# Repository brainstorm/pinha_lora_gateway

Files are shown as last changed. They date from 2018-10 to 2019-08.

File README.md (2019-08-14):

# Mini-PCIe LoRa Gateway with PMOD and POE

This small LoRa gateway adapter (75x41mm) is motivated by the generous donation of a (n-fuse)[https://www.n-fuse.co/]'s LoRaWan [concentrator card](https://www.n-fuse.co/devices/LoRaWAN-Concentrator-Card-mini-PCIe.html). **This version of the board is meant to work with the USB firmware for the n-fuse board**:

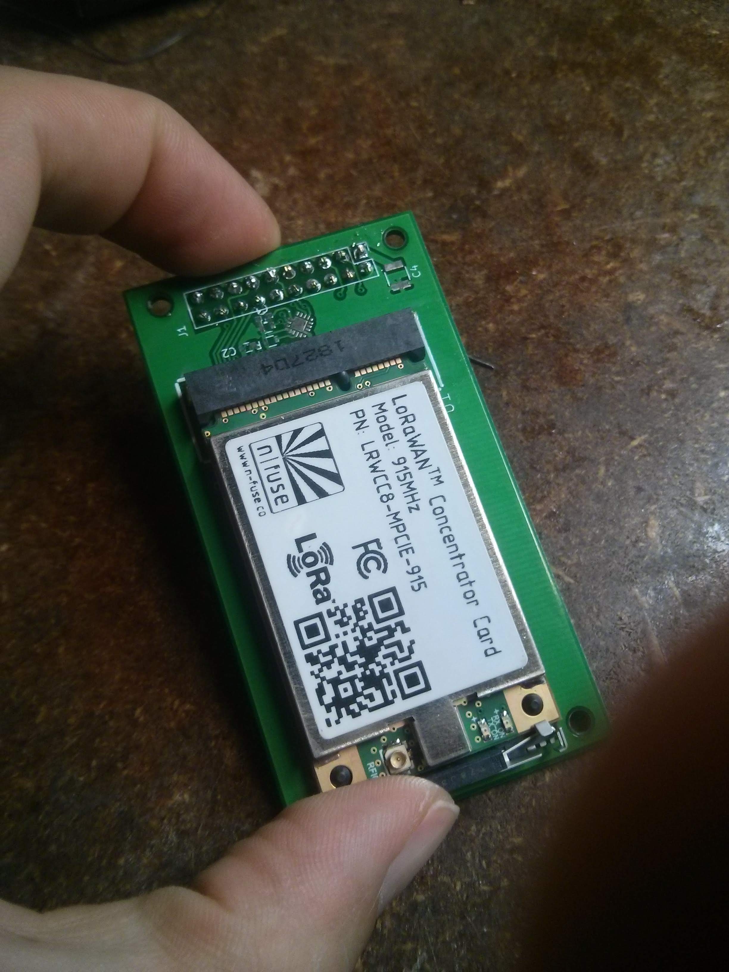
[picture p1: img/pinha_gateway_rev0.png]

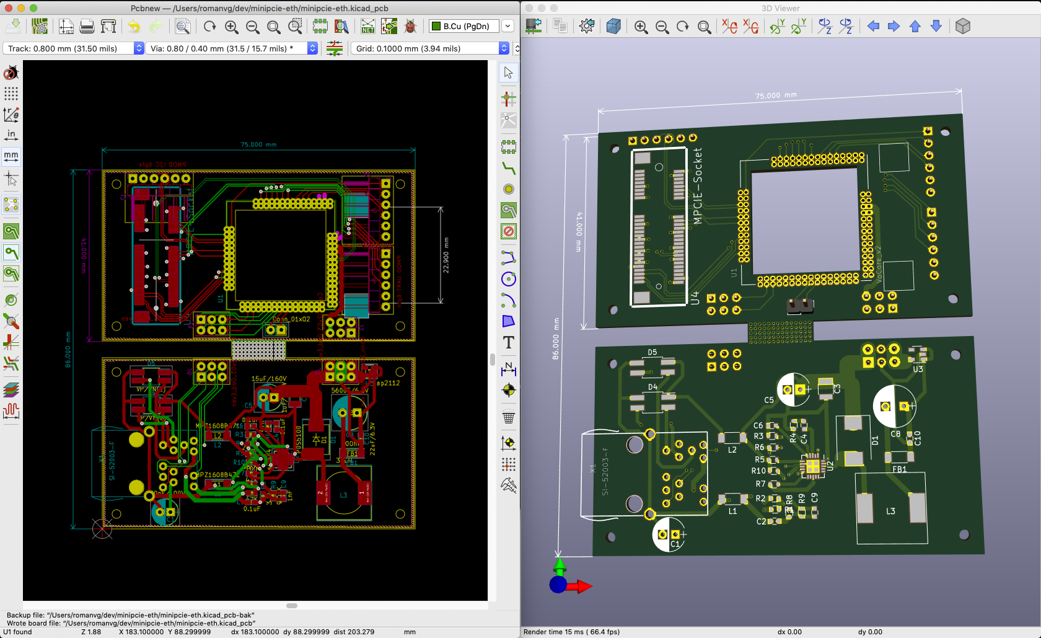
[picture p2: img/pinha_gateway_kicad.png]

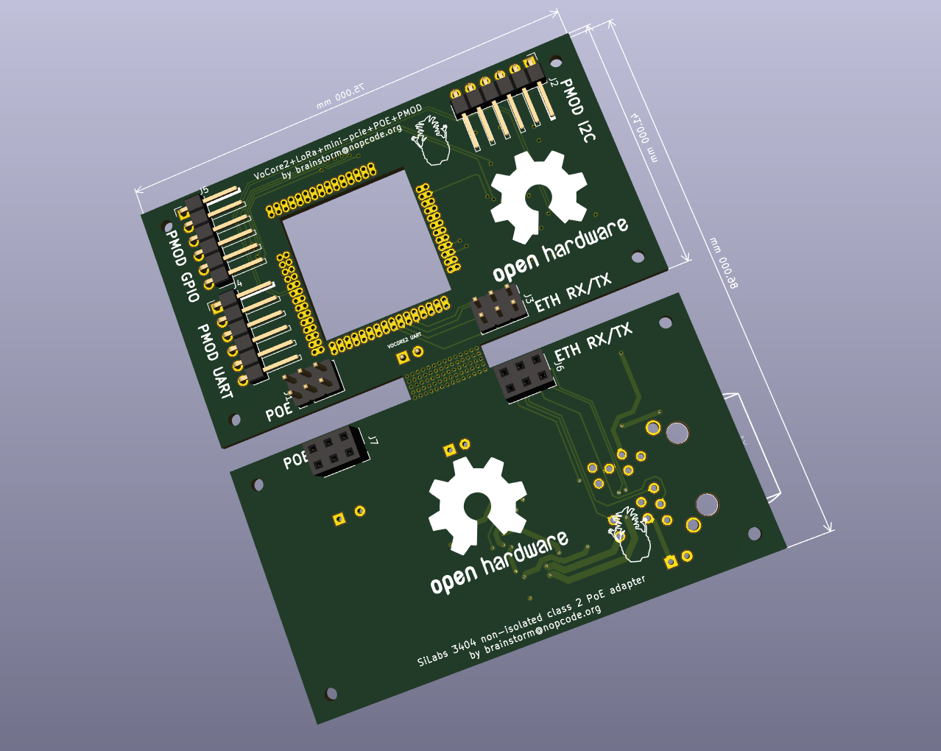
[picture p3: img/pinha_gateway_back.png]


Future versions might switch to the UART version of the n-fuse firmware.

RAK wireless boards might work with this adapter, but they are not tested... [I'm open to receive a RAKWireless board to try it out :)](https://twitter.com/RAKwireless/status/1138038732207087616?s=19).

The intention with this board is to have a maker-friendly LoRa gateway base design for modular gateways that incorporates the [PMOD flexibility](https://reference.digilentinc.com/_media/reference/pmod/pmod-interface-specification-1_2_0.pdf).

One could think it as a fusion of the following new developments (before they actually existed):

https://github.com/electroniceel/vocore2-breakout

https://m2m-tele.com/product/gw-01-poe/

# Software

There's the OpenWrt package that accompanies this work (and needs just a little bit more OSS love):

https://github.com/openwrt/packages/pull/8264

Which is pretty much a way to upstream the work shown by [Felix Wiedemann on hackster.io](https://www.hackster.io/fewi/build-a-lora-gateway-with-n-fuse-mpcie-card-71f0e1) with several UX improvements.

All in all, a neat experiment with 4 layer board design as a hobby while collaborating with a great company.

Thanks again n-fuse!

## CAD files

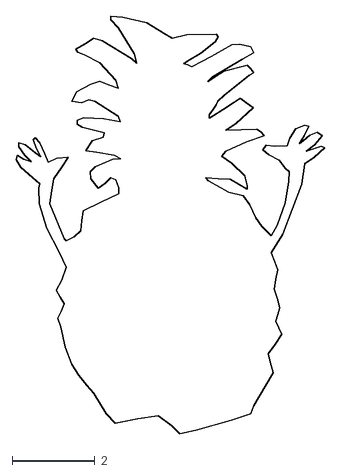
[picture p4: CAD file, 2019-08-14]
artwork/pinha-logo.dxf
7.46 x 10.1

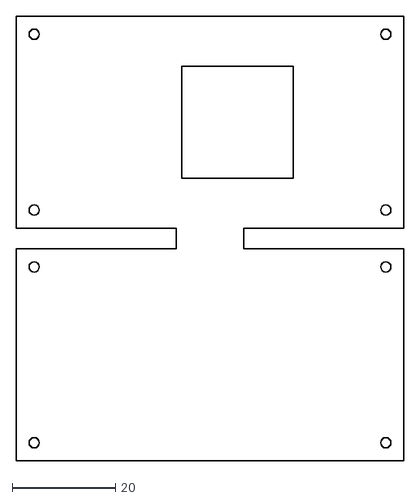
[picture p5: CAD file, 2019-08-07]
outline/vocore2_90degree.dxf
75.0 x 86.0

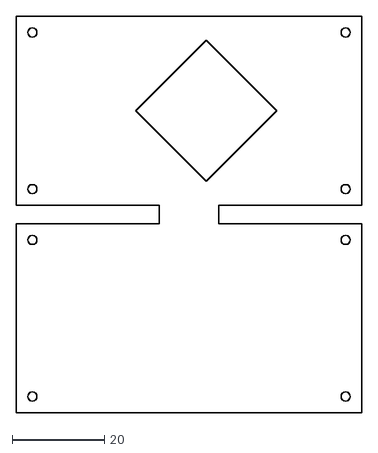
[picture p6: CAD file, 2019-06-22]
outline/vocore_minipcieth.dxf
75.0 x 86.0

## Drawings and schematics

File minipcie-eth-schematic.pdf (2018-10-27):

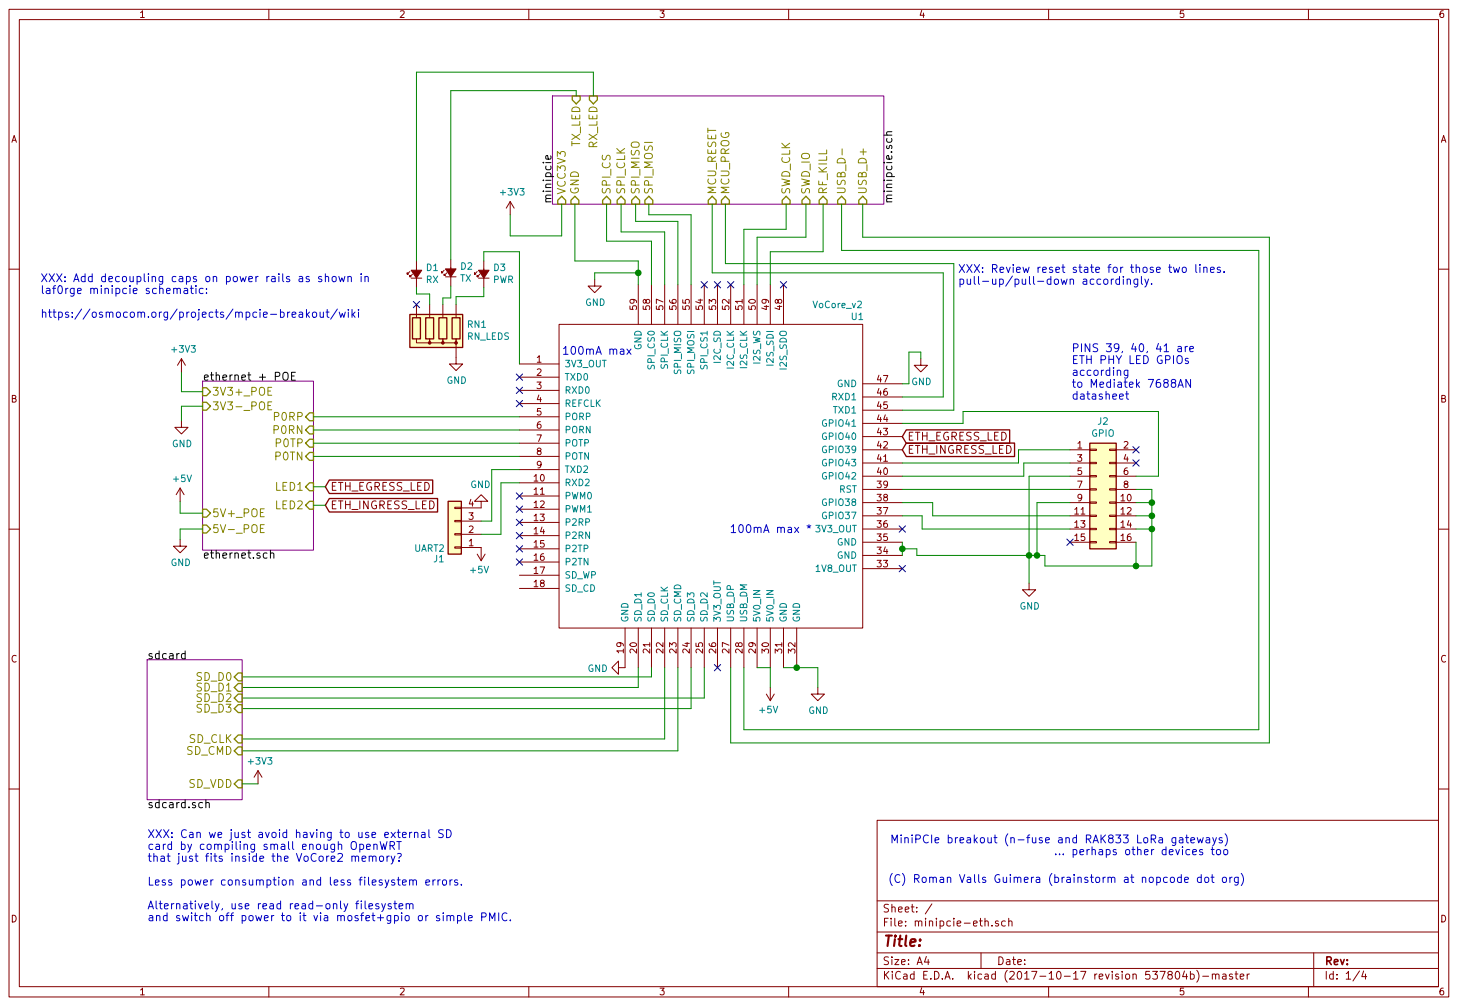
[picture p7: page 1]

laf0rge minipcie schematic:
https://osmocom.org/projects/mpcie-breakout/wiki sdcard

ETH PHY LED GPIOs
according
to Mediatek 7688AN

9 | | 10
11 | | 12
13 | | 14
15 | | 16

100mA max * XXX: Can we just avoid having to use external SD

(C) Roman Valls Guimera (brainstorm at nopcode dot org) GND

card by compiling small enough OpenWRT
that just fits inside the VoCore2 memory?
Less power consumption and less filesystem errors.
Alternatively, use read read-only filesystem
and switch off power to it via mosfet+gpio or simple PMIC.

perhaps other devices too

File: minipcie-eth.sch Sheet: /
Id: 1/4 Title:

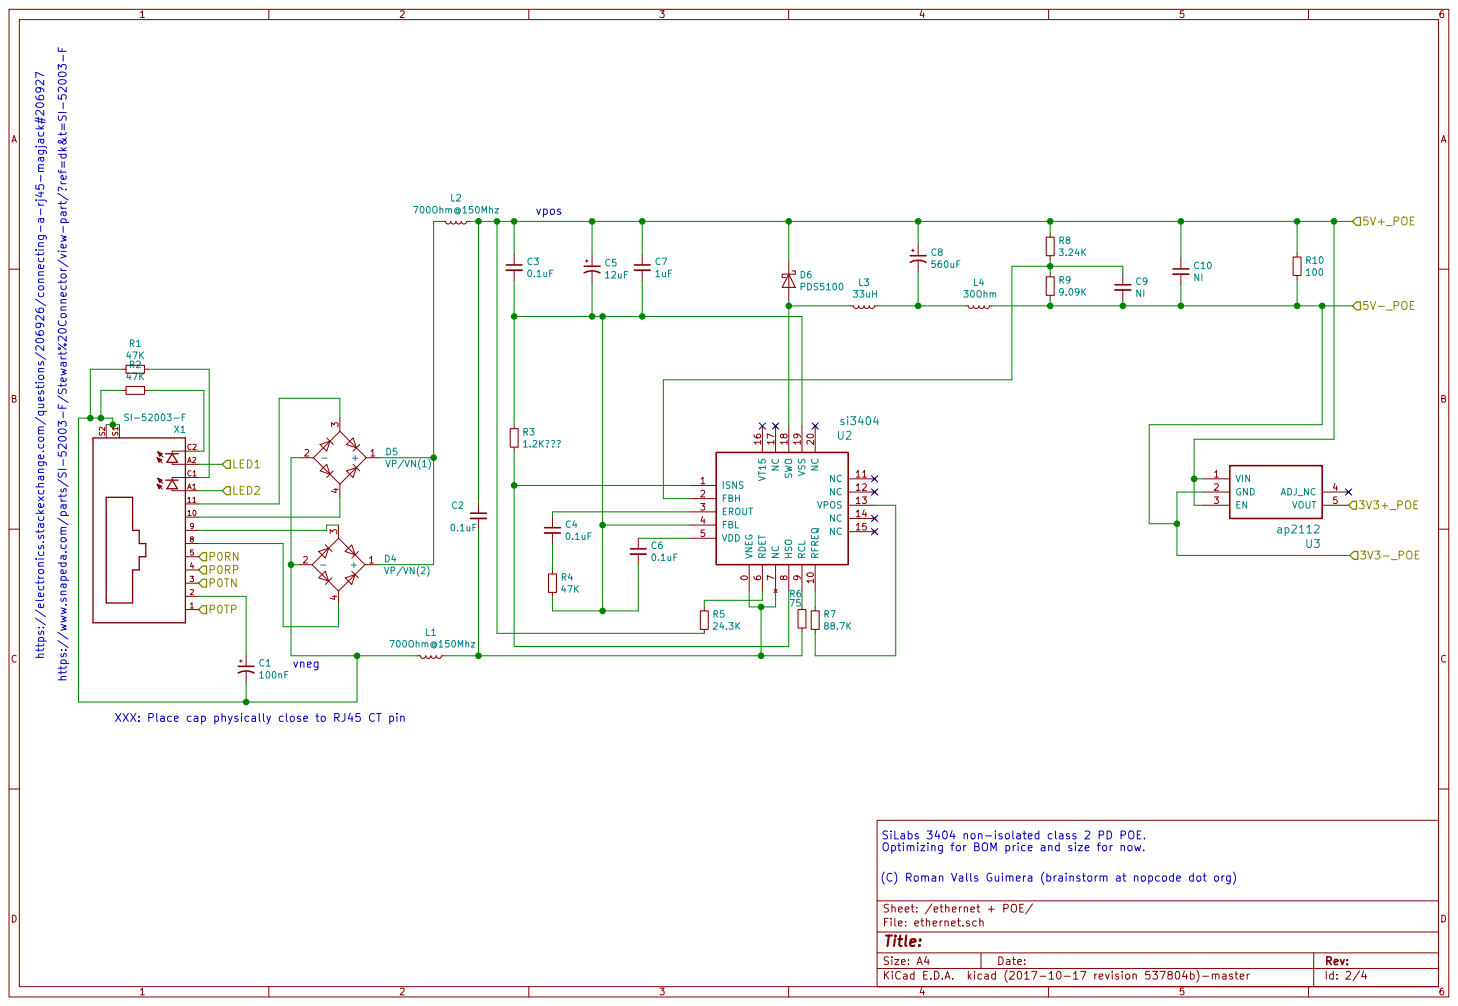
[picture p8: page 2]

100nF https://electronics.stackexchange.com/questions/206926/connecting-a-rj45-magjack#206927

Optimizing for BOM price and size for now. C2

(C) Roman Valls Guimera (brainstorm at nopcode dot org)

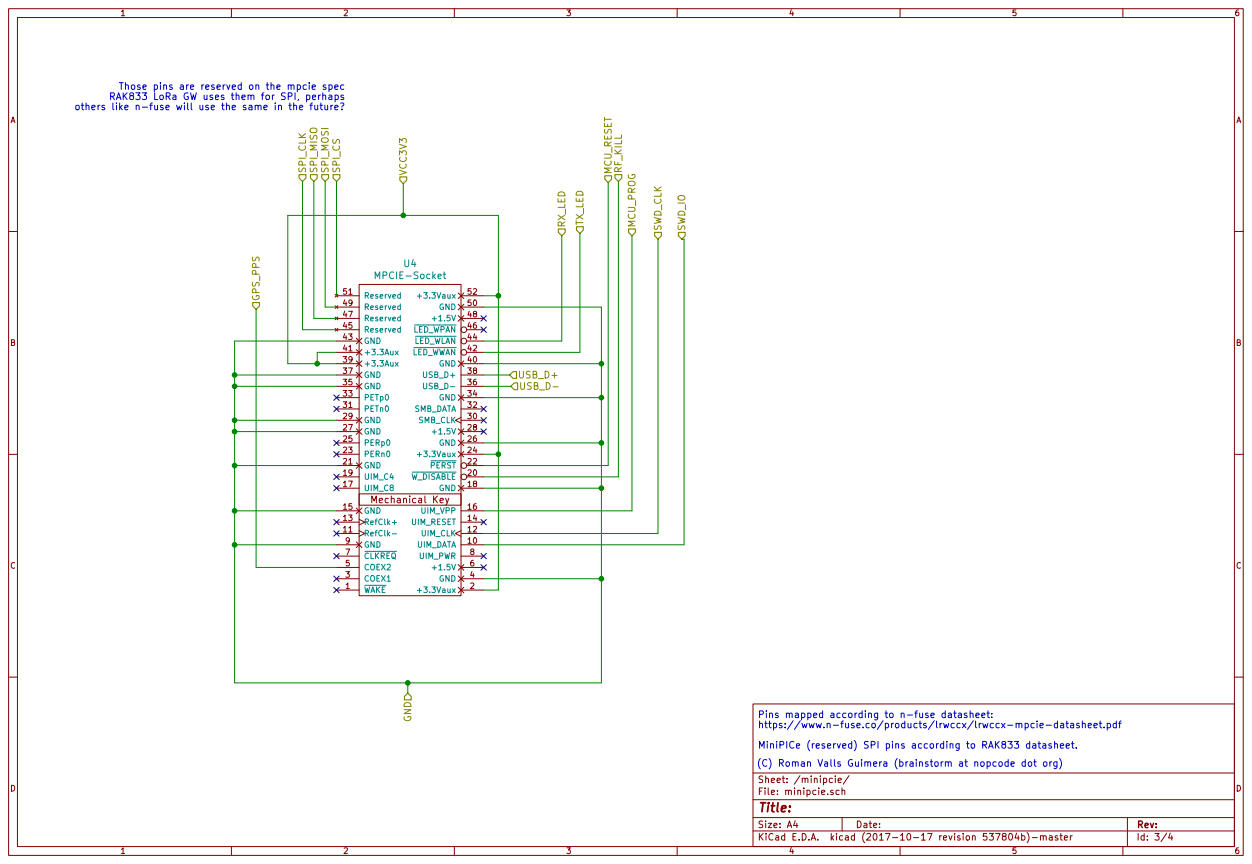
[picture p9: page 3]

Those pins are reserved on the mpcie spec
RAK833 LoRa GW uses them for SPI, perhaps others like n-fuse will use the same in the future?

https://www.n-fuse.co/products/lrwccx/lrwccx-mpcie-datasheet.pdf

(C) Roman Valls Guimera (brainstorm at nopcode dot org)
Sheet: /minipcie/
File: minipcie.sch
Id: 3/4 Title:

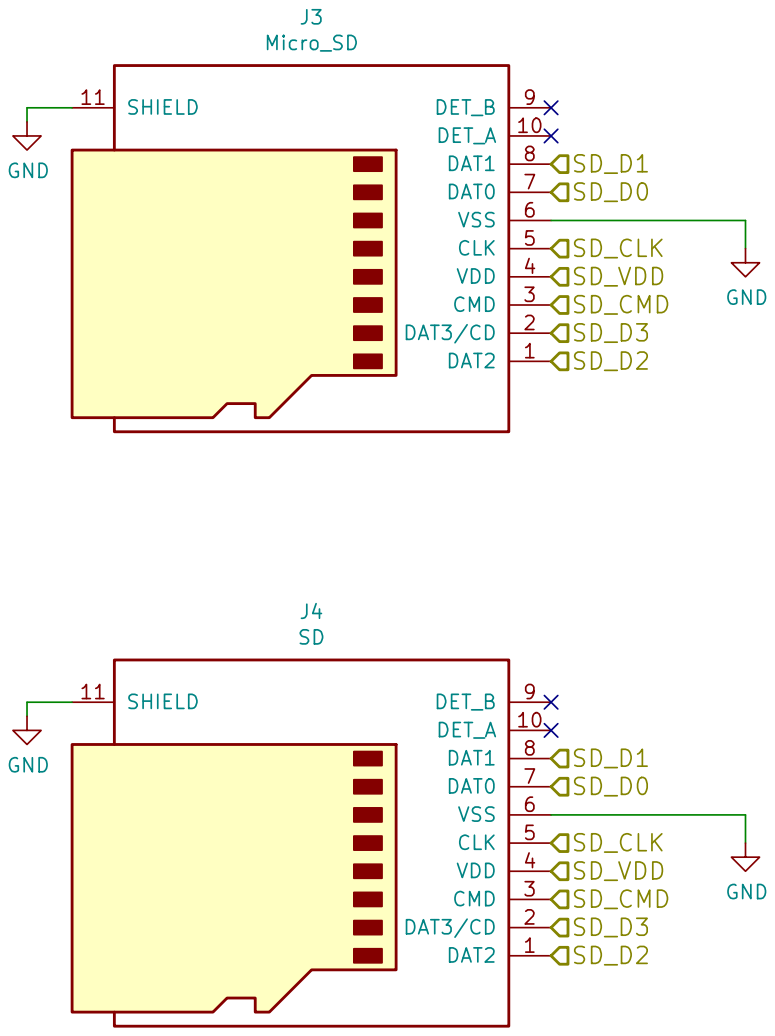
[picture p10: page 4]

Id: 4/4 Title: File: sdcard.sch Sheet: /sdcard/

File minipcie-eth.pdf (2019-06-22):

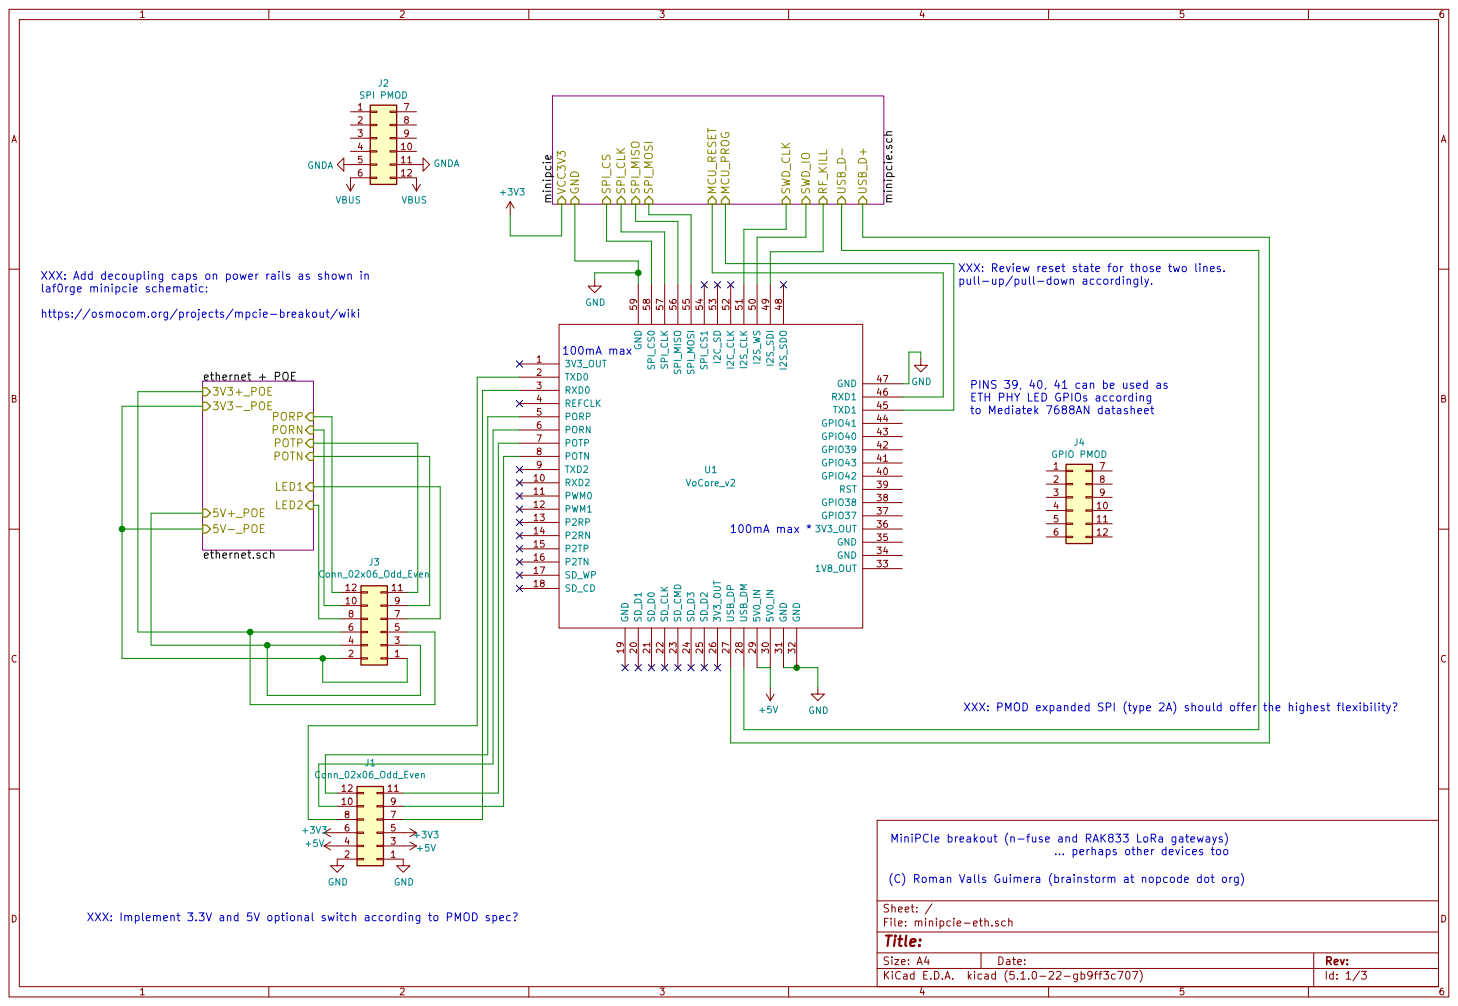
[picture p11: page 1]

+3V3 XXX: Add decoupling caps on power rails as shown in

ETH PHY LED GPIOs according

J4 GPIO PMOD XXX: Implement 3.3V and 5V optional switch according to PMOD spec?

perhaps other devices too

(C) Roman Valls Guimera (brainstorm at nopcode dot org)

File: minipcie-eth.sch Sheet: /
Id: 1/3 Title:

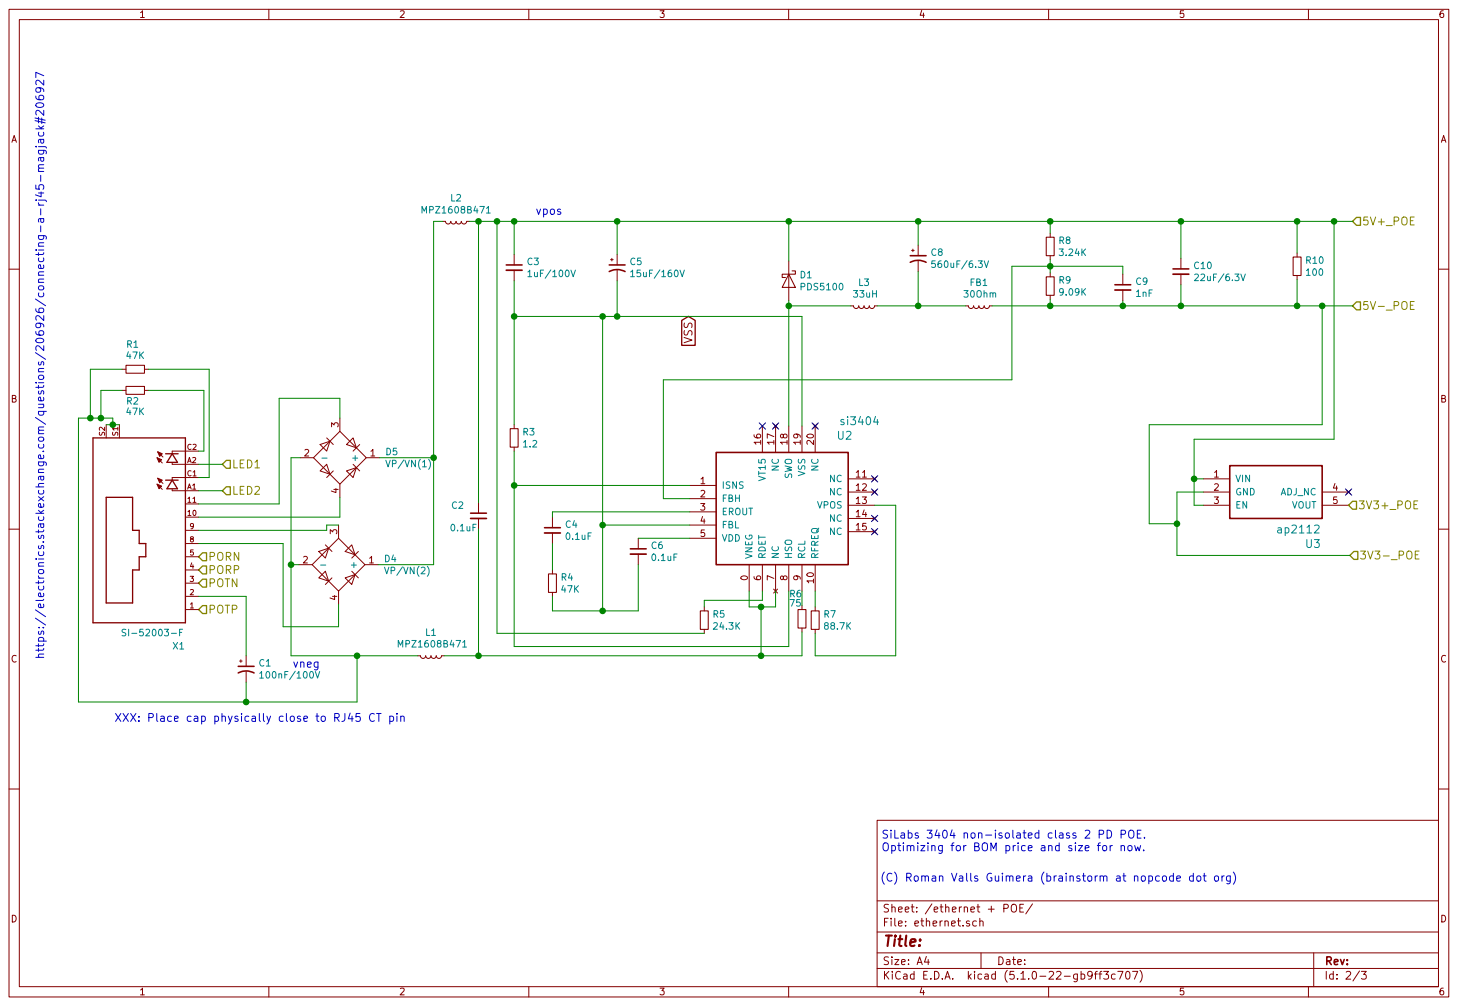
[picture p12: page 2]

100nF/100V https://electronics.stackexchange.com/questions/206926/connecting-a-rj45-magjack#206927

Optimizing for BOM price and size for now. C2

(C) Roman Valls Guimera (brainstorm at nopcode dot org)

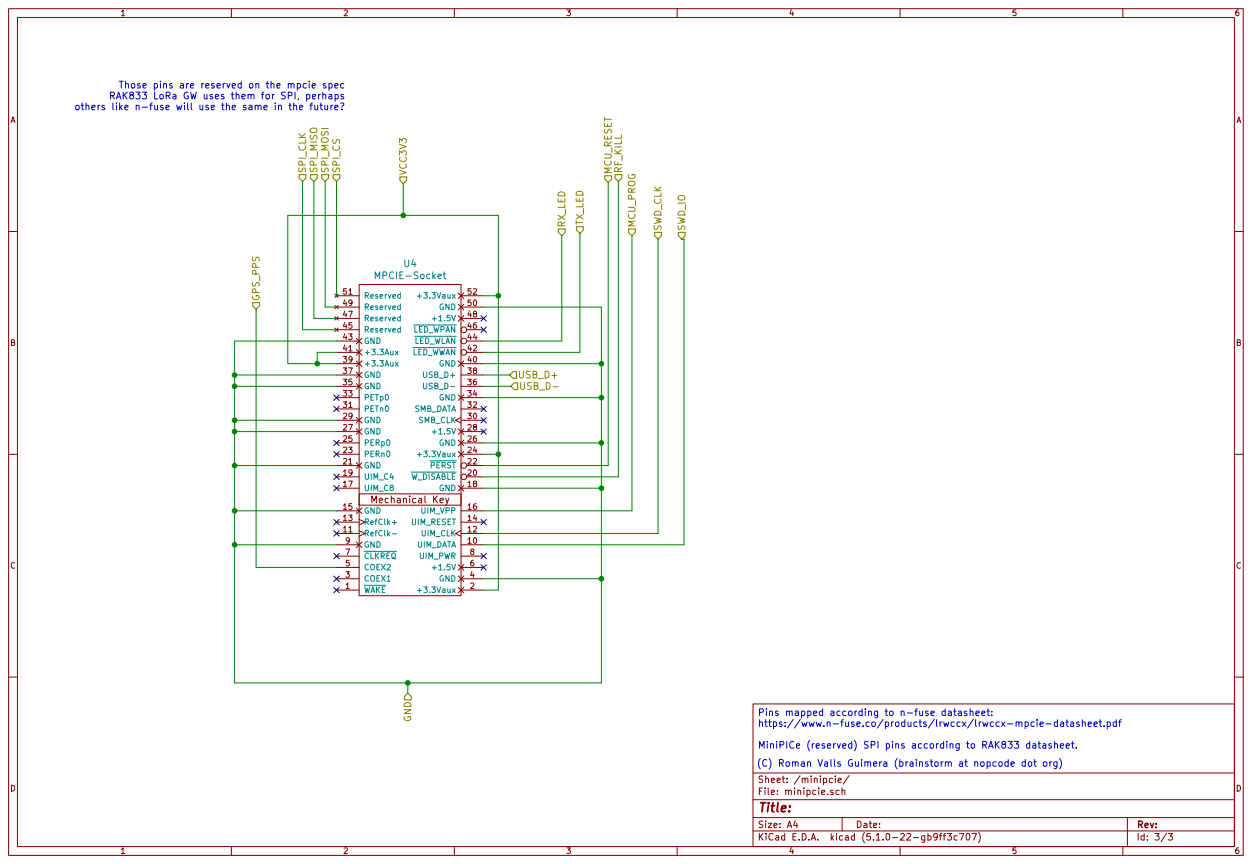
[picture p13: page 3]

Those pins are reserved on the mpcie spec
RAK833 LoRa GW uses them for SPI, perhaps others like n-fuse will use the same in the future?

https://www.n-fuse.co/products/lrwccx/lrwccx-mpcie-datasheet.pdf

(C) Roman Valls Guimera (brainstorm at nopcode dot org)
Sheet: /minipcie/
File: minipcie.sch
Id: 3/3 Title:

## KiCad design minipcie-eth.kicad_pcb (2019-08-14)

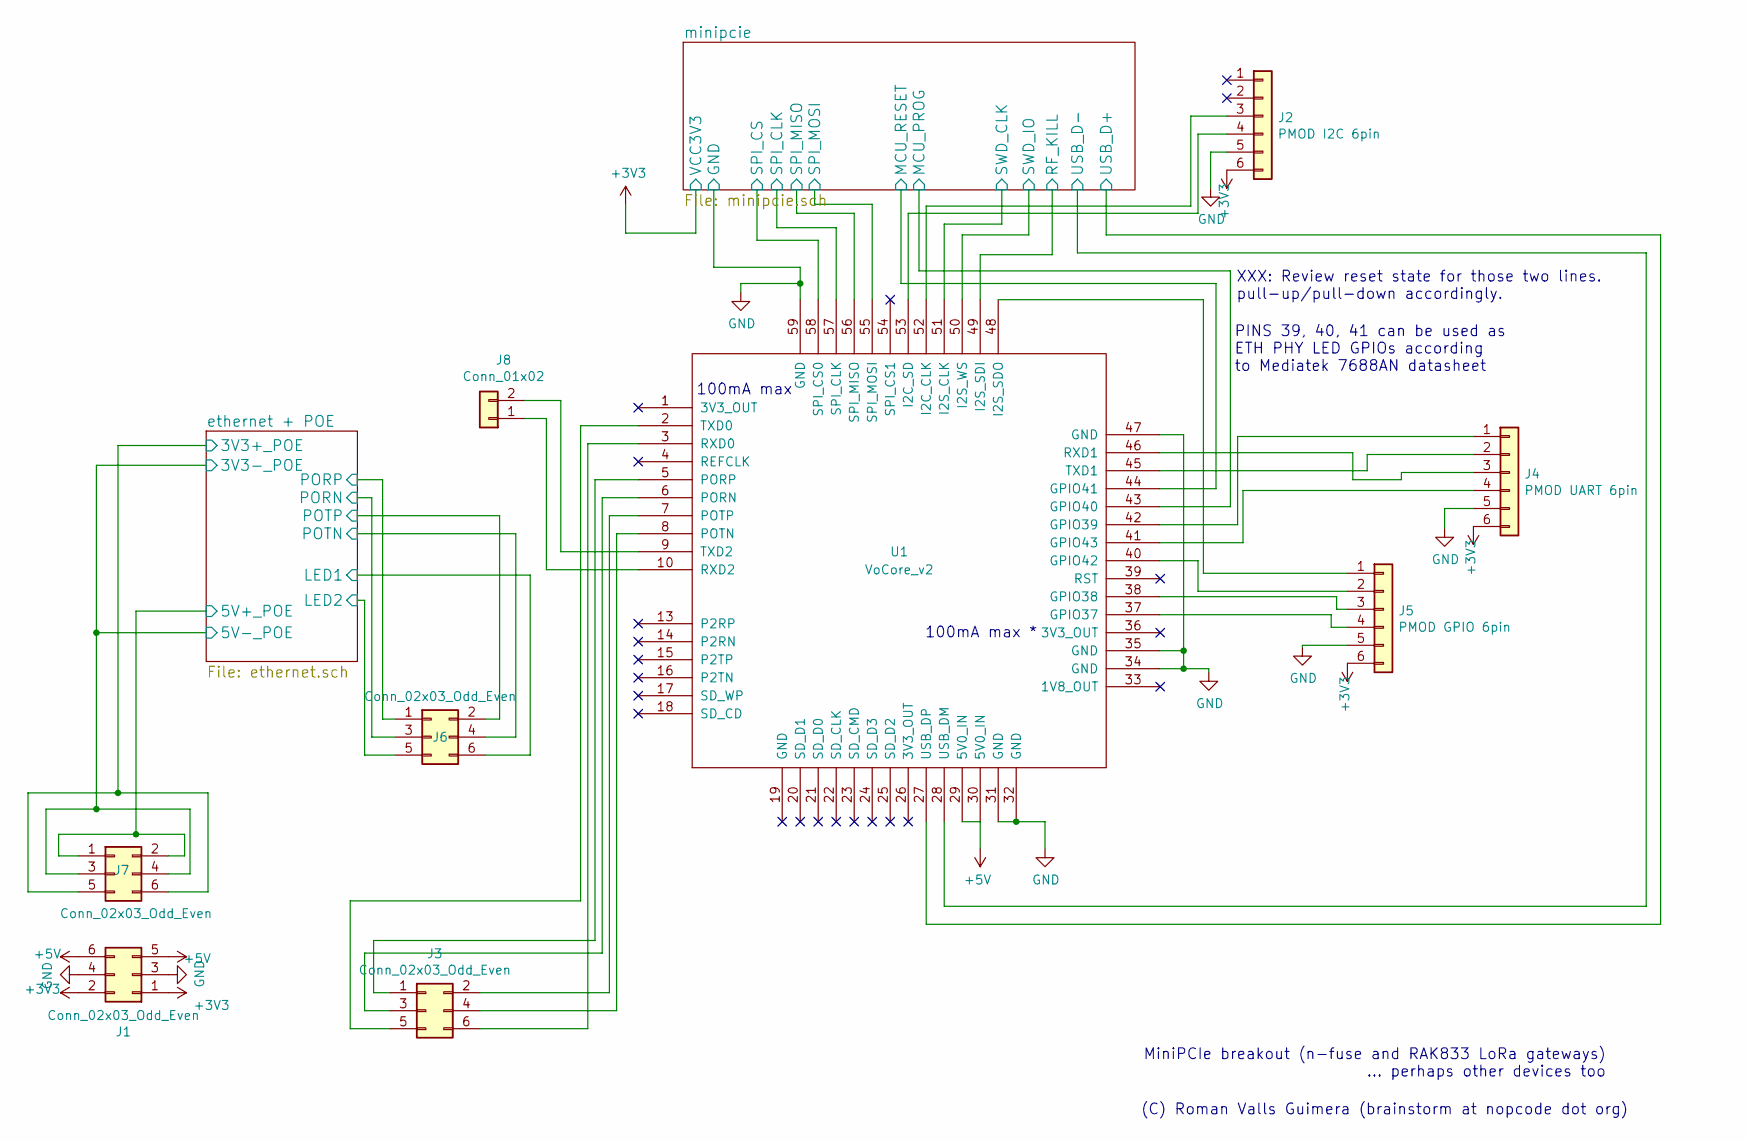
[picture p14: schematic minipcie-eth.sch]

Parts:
J1, J3: Conn_02x03_Odd_Even; PinHeader_2x03_P2.54mm_Vertical
J2: PMOD I2C 6pin; PinHeader_1x06_P2.54mm_Horizontal
J4: PMOD UART 6pin; PinHeader_1x06_P2.54mm_Horizontal
J5: PMOD GPIO 6pin; PinHeader_1x06_P2.54mm_Horizontal
J6, J7: Conn_02x03_Odd_Even; PinSocket_2x03_P2.54mm_Vertical
J8: Conn_01x02; PinHeader_1x02_P2.54mm_Vertical
U1: VoCore_v2; VOCORE2

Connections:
+3V3: J1.1, J1.2, J2.6, J4.6, J5.6; also elsewhere on the board
+5V: J1.5, J1.6, U1.29 (5V0_IN), U1.30 (5V0_IN)
/ethernet + POE/3V3+_POE: J7.5, J7.6; also elsewhere on the board
/ethernet + POE/3V3-_POE: J7.3, J7.4; also elsewhere on the board
/ethernet + POE/5V+_POE: J7.1, J7.2; also elsewhere on the board
/ethernet + POE/LED1: J6.6; also elsewhere on the board
/ethernet + POE/LED2: J6.5; also elsewhere on the board
/ethernet + POE/PORN: J6.3; also elsewhere on the board
/ethernet + POE/PORP: J6.1; also elsewhere on the board
/ethernet + POE/POTN: J6.4; also elsewhere on the board
/ethernet + POE/POTP: J6.2; also elsewhere on the board
/minipcie/MCU_PROG: U1.43 (GPIO40); also elsewhere on the board
/minipcie/MCU_RESET: U1.44 (GPIO41); also elsewhere on the board
/minipcie/RF_KILL: U1.49 (I2S_SDI); also elsewhere on the board
/minipcie/SPI_CLK: U1.57 (SPI_CLK); also elsewhere on the board
/minipcie/SPI_CS: U1.58 (SPI_CS0); also elsewhere on the board
/minipcie/SPI_MISO: U1.56 (SPI_MISO); also elsewhere on the board
/minipcie/SPI_MOSI: U1.55 (SPI_MOSI); also elsewhere on the board
/minipcie/SWD_CLK: U1.51 (I2S_CLK); also elsewhere on the board
/minipcie/SWD_IO: U1.50 (I2S_WS); also elsewhere on the board
/minipcie/USB_D+: U1.27 (USB_DP); also elsewhere on the board
/minipcie/USB_D-: U1.28 (USB_DM); also elsewhere on the board
GND: J1.3, J1.4, J2.5, J4.5, J5.5, U1.31 (GND), U1.32 (GND), U1.34 (GND), U1.35 (GND), U1.47 (GND), U1.59 (GND); also elsewhere on the board
unnamed: J2.3, U1.52 (I2C_CLK)
unnamed: J2.4, U1.53 (I2C_SD)
unnamed: J3.1, U1.5 (PORP)
unnamed: J3.2, U1.7 (POTP)
unnamed: J3.3, U1.6 (PORN)
unnamed: J3.4, U1.8 (POTN)
unnamed: J3.5, U1.2 (TXD0)
unnamed: J3.6, U1.3 (RXD0)
unnamed: J4.1, U1.42 (GPIO39)
unnamed: J4.2, U1.45 (TXD1)
unnamed: J4.3, U1.46 (RXD1)
unnamed: J4.4, U1.41 (GPIO43)
unnamed: J5.1, U1.48 (I2S_SDO)
unnamed: J5.2, U1.40 (GPIO42)
unnamed: J5.3, U1.38 (GPIO38)
unnamed: J5.4, U1.37 (GPIO37)
unnamed: J8.1, U1.10 (RXD2)
unnamed: J8.2, U1.9 (TXD2)

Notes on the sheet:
PINS 39, 40, 41 can be used as ETH PHY LED GPIOs according to Mediatek 7688AN datasheet
100mA max
MiniPCIe breakout (n-fuse and RAK833 LoRa gateways) … perhaps other devices too
100mA max *
XXX: Review reset state for those two lines. pull-up/pull-down accordingly.
(C) Roman Valls Guimera (brainstorm at nopcode dot org)

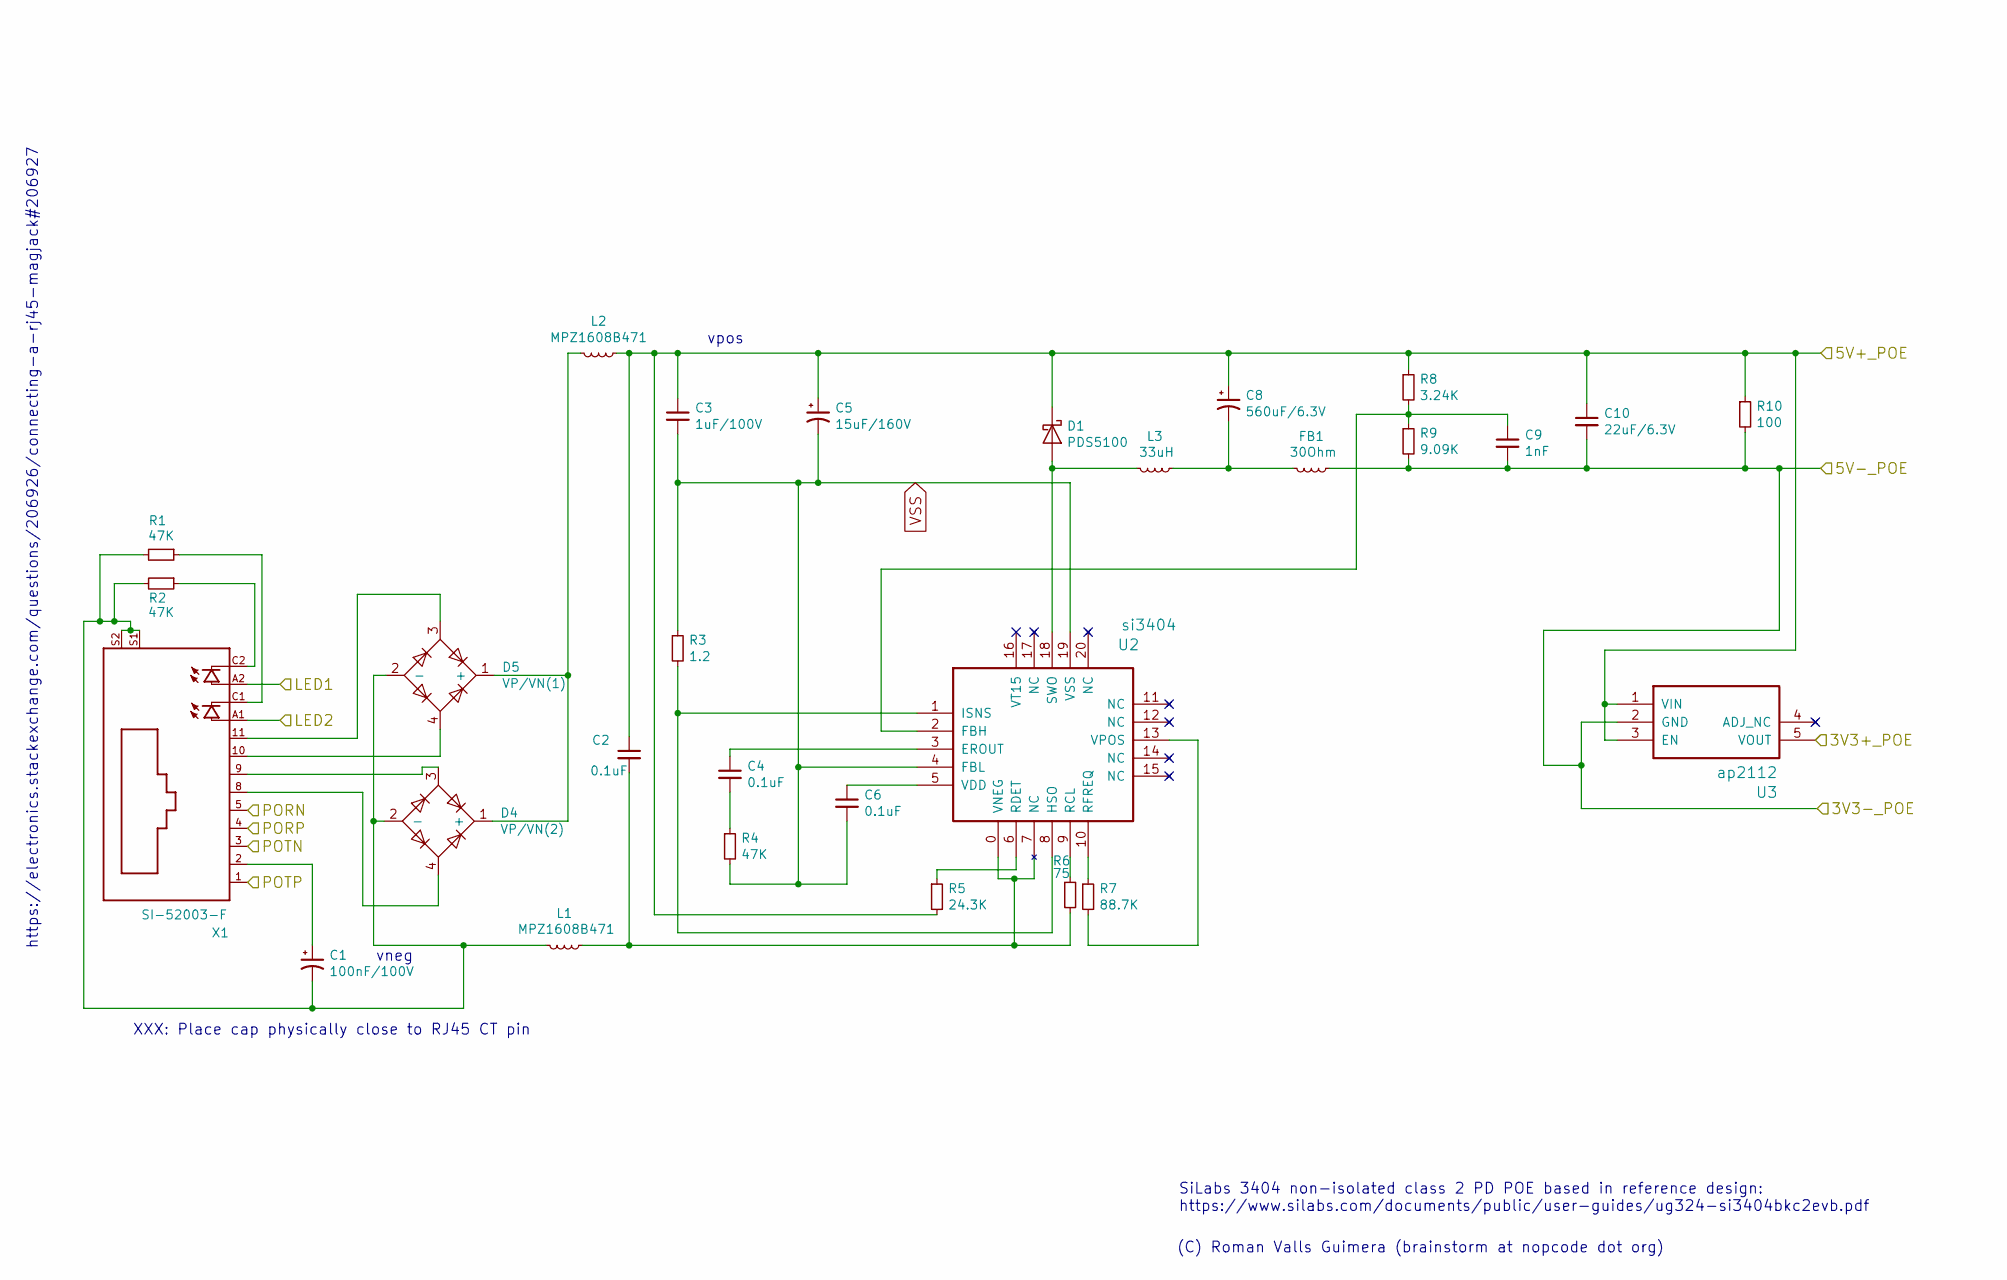
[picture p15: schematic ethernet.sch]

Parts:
C1: 100nF/100V; CP_Radial_D6.3mm_P2.50mm
C2, C4, C6: 0.1uF; C_0603
C3: 1uF/100V; C_1210
C5: 15uF/160V; CP_Radial_D6.3mm_P2.50mm
C8: 560uF/6.3V; CP_Radial_D8.0mm_P3.50mm
C9: 1nF; C_0603
C10: 22uF/6.3V; C_0603
D1: PDS5100; D_SMC
D4: VP/VN(2); Socket_Strip_Straight_2x02_Pitch2.00mm_SMD
D5: VP/VN(1); Socket_Strip_Straight_2x02_Pitch2.00mm_SMD
FB1: 30Ohm; L_1806
L1, L2: MPZ1608B471; L_1806
L3: 33uH; L_Neosid_SM-NE127
R1, R2, R4: 47K; R_0603
R3: 1.2; R_0603
R5: 24.3K; R_0603
R6: 75; R_0603
R7: 88.7K; R_0603
R8: 3.24K; R_0603
R9: 9.09K; R_0603
R10: 100; R_0603
U2: si3404; QFN-20-1EP_4x4mm_Pitch0.5mm
U3: ap2112; SOT-23-5
X1: SI-52003-F

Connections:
/ethernet + POE/3V3+_POE: U3.5 (VOUT); also elsewhere on the board
/ethernet + POE/3V3-_POE: C9.2, C10.2, FB1.1, R9.2, R10.2, U3.2 (GND); also elsewhere on the board
/ethernet + POE/5V+_POE: C2.1, C3.1, C5.1, C8.1, C10.1, D1.1 (K), L2.1, R5.2, R8.1, R10.1, U3.1 (VIN), U3.3 (EN); also elsewhere on the board
/ethernet + POE/LED1: X1.A2; also elsewhere on the board
/ethernet + POE/LED2: X1.A1; also elsewhere on the board
/ethernet + POE/PORN: X1.5 (RD-); also elsewhere on the board
/ethernet + POE/PORP: X1.4 (RD+); also elsewhere on the board
/ethernet + POE/POTN: X1.3 (TD-); also elsewhere on the board
/ethernet + POE/POTP: X1.1 (TD+); also elsewhere on the board
unnamed: C1.1, X1.2 (CT)
unnamed: C1.2, D4.2 (-), D5.2 (-), L1.2, R1.2, R2.2, X1.S1, X1.S2
unnamed: C2.2, L1.1, R6.2, U2.0 (VNEG), U2.7 (NC)
unnamed: C4.1, U2.3 (EROUT)
unnamed: C4.2, R4.1
unnamed: C6.1, U2.5 (VDD)
unnamed: C8.2, FB1.2, L3.1
unnamed: C9.1, R8.2, R9.1
unnamed: D1.2 (A), L3.2, U2.18 (SWO)
unnamed: D4.1 (+), D5.1 (+), L2.2
unnamed: D4.3, X1.9 (VC1-)
unnamed: D4.4, X1.8 (VC1+)
unnamed: D5.3, X1.11 (VC2-)
unnamed: D5.4, X1.10 (VC2+)
unnamed: R1.1, X1.C1
unnamed: R2.1, X1.C2
unnamed: R3.2, U2.1 (ISNS), U2.8 (HSO)
unnamed: R5.1, U2.6 (RDET)
unnamed: R6.1, U2.9 (RCL)
unnamed: R7.1, U2.10 (RFREQ)
unnamed: R7.2, U2.13 (VPOS)
VSS: C3.2, C5.2, C6.2, R3.1, R4.2, U2.4 (FBL), U2.19 (VSS)

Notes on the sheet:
https://electronics.stackexchange.com/questions/206926/connecting-a-rj45-magjack#206927
XXX: Place cap physically close to RJ45 CT pin
SiLabs 3404 non-isolated class 2 PD POE based in reference design: https://www.silabs.com/documents/public/user-guides/ug324-si3404bkc2evb.pdf
vneg
vpos
(C) Roman Valls Guimera (brainstorm at nopcode dot org)

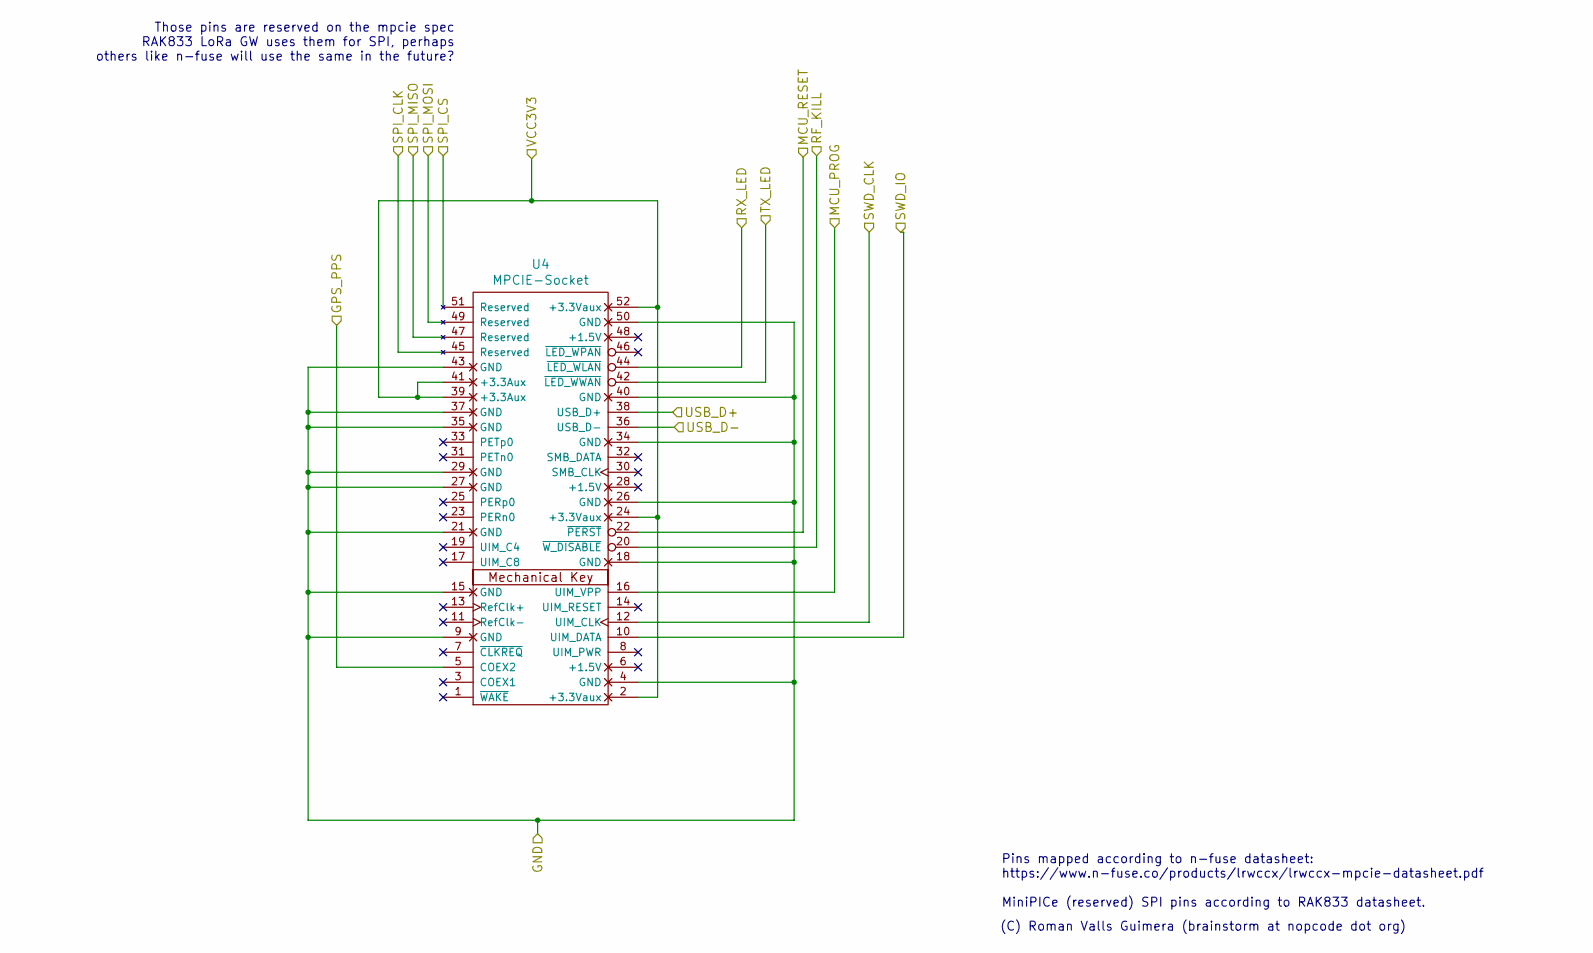
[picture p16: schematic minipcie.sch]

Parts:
U4: MPCIE-Socket; mpcie-socket

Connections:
+3V3: U4.2 (+3.3Vaux), U4.24 (+3.3Vaux), U4.39 (+3.3Aux), U4.41 (+3.3Aux), U4.52 (+3.3Vaux); also elsewhere on the board
/minipcie/MCU_PROG: U4.16 (UIM_VPP); also elsewhere on the board
/minipcie/MCU_RESET: U4.22 (~PERST); also elsewhere on the board
/minipcie/RF_KILL: U4.20 (~W_DISABLE); also elsewhere on the board
/minipcie/SPI_CLK: U4.45 (Reserved); also elsewhere on the board
/minipcie/SPI_CS: U4.51 (Reserved); also elsewhere on the board
/minipcie/SPI_MISO: U4.47 (Reserved); also elsewhere on the board
/minipcie/SPI_MOSI: U4.49 (Reserved); also elsewhere on the board
/minipcie/SWD_CLK: U4.12 (UIM_CLK); also elsewhere on the board
/minipcie/SWD_IO: U4.10 (UIM_DATA); also elsewhere on the board
/minipcie/USB_D+: U4.38 (USB_D+); also elsewhere on the board
/minipcie/USB_D-: U4.36 (USB_D-); also elsewhere on the board
GND: U4.4 (GND), U4.9 (GND), U4.15 (GND), U4.18 (GND), U4.21 (GND), U4.26 (GND), U4.27 (GND), U4.29 (GND), U4.34 (GND), U4.35 (GND), U4.37 (GND), U4.40 (GND), U4.43 (GND), U4.50 (GND); also elsewhere on the board

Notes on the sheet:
Pins mapped according to n-fuse datasheet: https://www.n-fuse.co/products/lrwccx/lrwccx-mpcie-datasheet.pdf MiniPICe (reserved) SPI pins according to RAK833 datasheet.
Those pins are reserved on the mpcie spec RAK833 LoRa GW uses them for SPI, perhaps others like n-fuse will use the same in the future?
(C) Roman Valls Guimera (brainstorm at nopcode dot org)

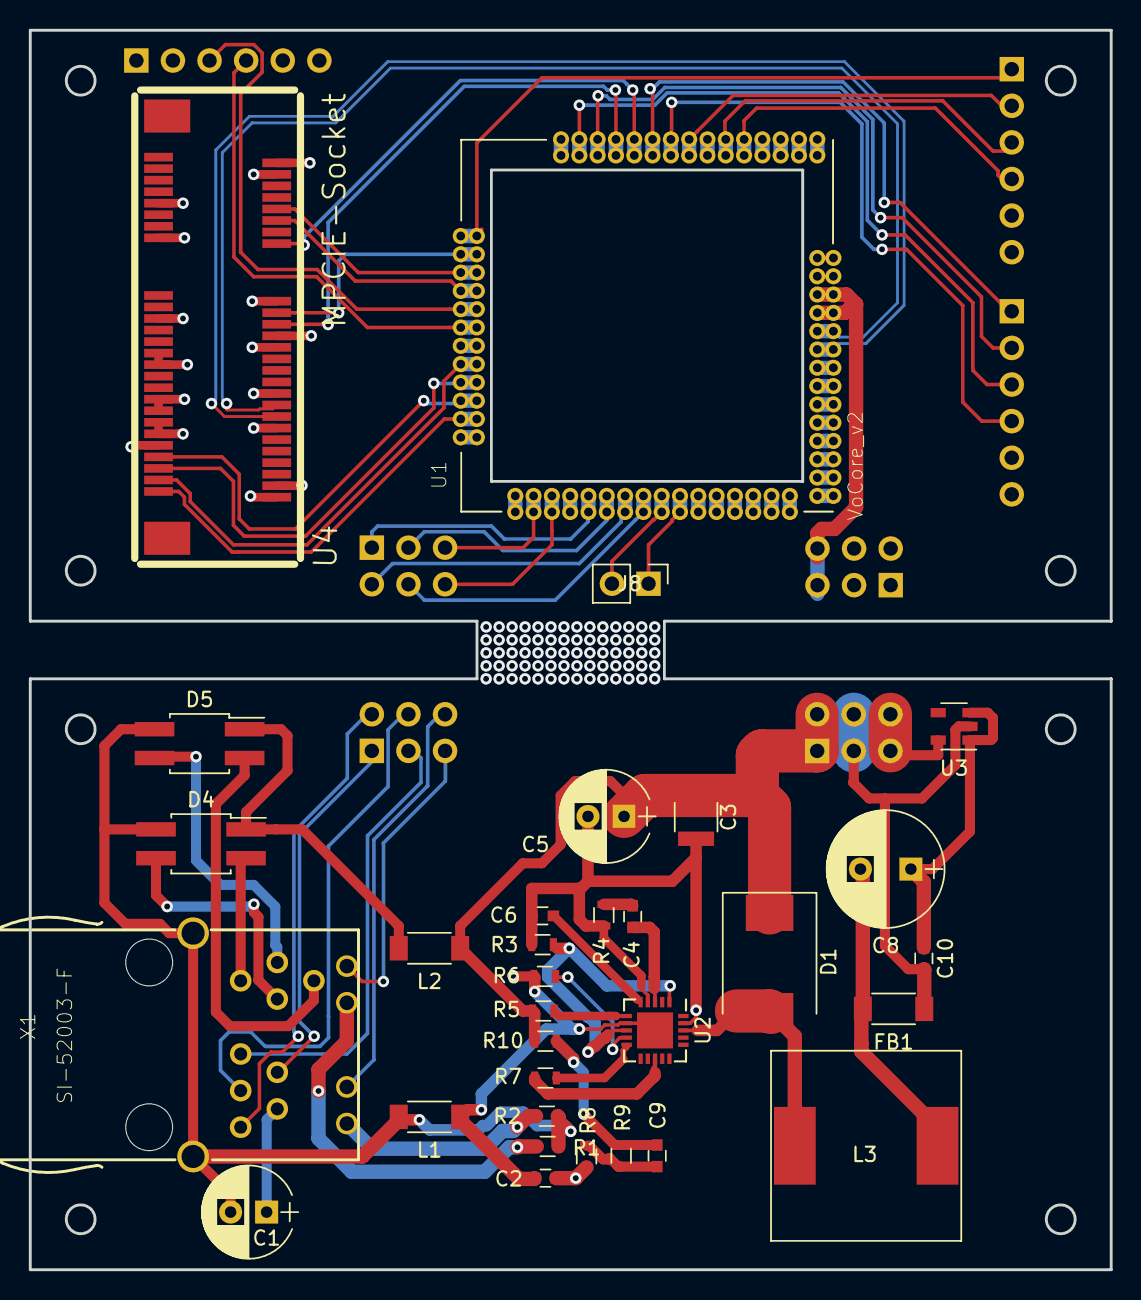
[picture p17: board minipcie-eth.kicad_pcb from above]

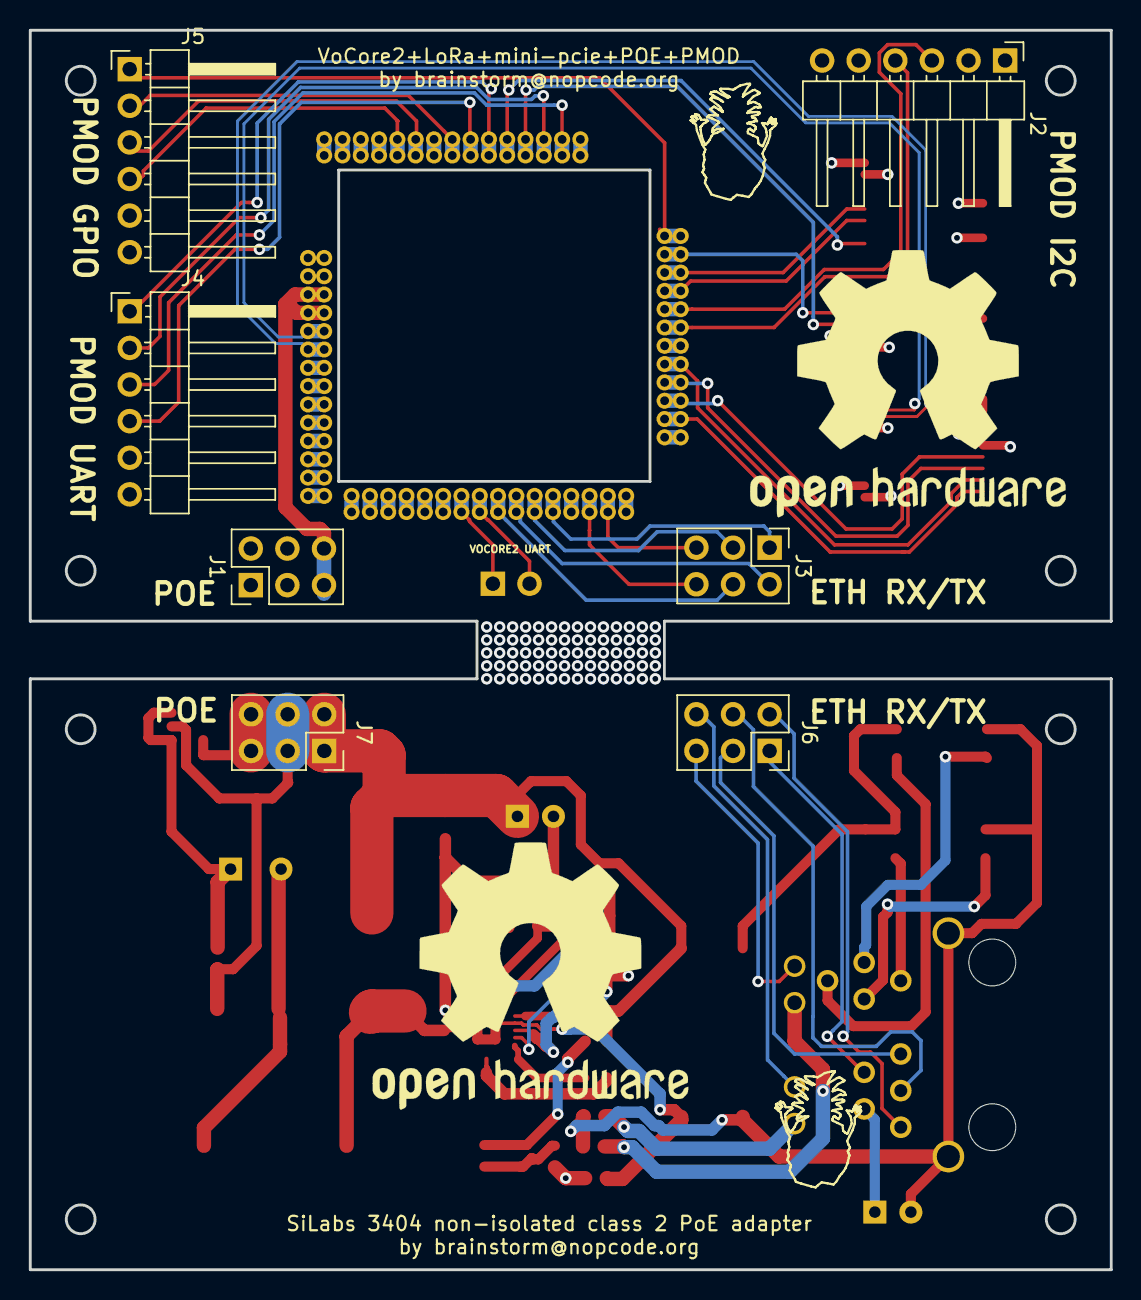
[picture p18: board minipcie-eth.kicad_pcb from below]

Board: 4 copper layers, 75.0 x 86.0 mm, 39 parts (7 on the bottom side), 63 nets.

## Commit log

2018-10-12 Initial commit, will go for si3406 for POE
    [ethernet.sch, minipcie-eth.kicad_pcb, minipcie-eth.sch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]
2018-10-13 Add all POE logic with the si3404, schematic almost finished.
    [ap2112.csv, ethernet.sch, minipcie-eth.sch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]
2018-10-14 Added SDcard wiring
    [minipcie-eth.sch, minipcie.sch, sdcard.sch]
2018-10-27 Rearrange components, validate package sizes, think about power plane placement since the ref design is 4 layers... can I add snubbers and other filtering and avoid 4-layer design?
    [ethernet.sch, minipcie-eth.kicad_pcb, minipcie-eth.sch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]
2018-10-27 Correct main coil (from coilcraft) footprint
    [ethernet.sch, minipcie-eth.kicad_pcb]
2018-10-28 Good discussion with Rob Powers about price margins for 2 layer PCB boards vs 4 layer PCBs... no market for that so closing this project and moving to a wESP32-based (or VoCore2) board :-S
    [ethernet.sch, sdcard.sch]
2019-03-17 Migrate to KiCad 5.1 :)
    [ethernet.sch, minipcie-eth.kicad_pcb, minipcie-eth.sch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]
2019-03-31 Migrate to board cuts/outline with hole for the VoCore
    [ethernet-2019-03-17-14-52-15.sch, minipcie-2019-03-17-14-52-15.sch, minipcie-eth-2019-03-17-14-52-15.sch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]
2019-04-20 Move libs away from rescue. Re-constrained board layout since cutouts were not perpendicular (overconstrained)
    [ethernet-2019-03-17-14-52-15.sch, ethernet.sch, minipcie-2019-03-17-14-52-15.sch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]
2019-04-20 Add snapeda vocore2 lib
    [vocore_minipcieth.dxf]
2019-04-20 Mirrored board layout to accomodate the silabs companion board
    [minipcie-eth.kicad_pcb, vocore_minipcieth.dxf]
2019-06-22 Added PMOD 6 header pins, mouse bites, copper fills for main board
    [minipcie-eth.kicad_pcb, minipcie-eth.sch, vocore_minipcieth.dxf]
2019-06-22 Initial 2-layer board routing proves unfeasible, switching to 4-layer design instead
    [minipcie-eth.kicad_pcb]
2019-06-23 Mainboard routing finished with 4 layers. Status update sent to n-fuse
    [minipcie-eth.kicad_pcb]
2019-07-14 Decided, I will switch to isolated si34061 design since the power budget and isolation are a bit too tight on the si3404... might change it all with the TPS23750 (https://www.ti.com/lit/ds/symlink/tp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
    [ethernet.sch, minipcie-eth.kicad_pcb]
2019-07-14 No, go for si3404 first, the power budget is tight, but it can work and be significantly cheaper
    [minipcie-eth.kicad_pcb, minipcie-eth.sch]
2019-08-07 Switch to 90 degree orientation of the VoCore2. Separate 2.54mm pin headers into two 6-pin connectors, separating data and power, ready to re-route
    [minipcie-eth.kicad_pcb, minipcie-eth.sch, vocore_minipcieth.dxf]
2019-08-07 Add exported outlines
    [vocore2_90degree.dxf, vocore_minipcieth.dxf]
2019-08-10 Rearrangement to 90 degrees for the VoCore and routing complete. Fighting last 5 DRC violations and then on to double-checking dimensions and clearances
    [minipcie-eth.kicad_pcb, minipcie-eth.sch]
2019-08-10 Re-routed USB_D- renaming pads so that the differential router did not get confused with multiple pads with the same name. Also removed ghost tracks for USB_D- and RF Kill
    [minipcie-eth.kicad_pcb]
2019-08-11 Routing finished, some of the si3404 application notes and via stitching ignored, to revisit later on
    [minipcie-eth.kicad_pcb]
2019-08-14 Some fun with credits and logos
    [minipcie-eth.kicad_pcb, pinha-logo.dxf]
2019-08-14 Add README and some nice pictures
    [minipcie-eth.kicad_pcb, minipcie-eth.sch, sdcard.sch]
2019-08-14 Some minor final tweaks... holes for the standoffs for the minipci-e card are still missing :facepalm:
    [minipcie-eth.kicad_pcb]
